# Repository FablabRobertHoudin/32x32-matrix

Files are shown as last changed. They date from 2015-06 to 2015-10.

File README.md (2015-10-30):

# Afficheur LED 32x32 disponible au Fablab

Base information: "RGB Panel Hookup Guide"
https://learn.sparkfun.com/tutorials/rgb-panel-hookup-guide

- Arduino sketch

ESP_32x32.ino 
Support affichage, connection internet en Wifi (2 réseau possible: perso / fablab par ex)
Recupère l'heure en NTP
Affiche les messages publiés par les utilisateurs (PubNub), grace à l'appli Android (APK)

- ESP-12e

Schéma disponible PDF
Attention à l'alimentation:
matrice en 5V (prise USB par ex)
ESP en 3.3V avec régulateur + condensateur 100µF.

http://esp8266.ru/esp8266-pin-register-strapping/

GPIO 0,2,4,5, 12-16 + 9-10 + 1,3 (USART)

GPIO9-10: 
http://smarpl.com/content/esp8266-esp-201-module-freeing-gpio9-and-gpio10

http://www.instructables.com/id/ARDUINO-SOLAR-CHARGE-CONTROLLER-Version-30/

- Application Android

Version très basique, APK dispo

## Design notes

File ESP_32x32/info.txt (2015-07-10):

AT+GMR
AT version:0.23.0.0(Apr 24 2015 21:11:01)
SDK version:1.0.1
Ai-Thinker Technology Co. Ltd.
Apr 27 2015 13:55:14

R0 G0 B0 : top half of display
R1 G1 B1 : bottom half of display
A, B, C, D: which two rows 
LAT(STB): mark end of row data
CLK: mark arrival of data
OE: switch off when one row to next

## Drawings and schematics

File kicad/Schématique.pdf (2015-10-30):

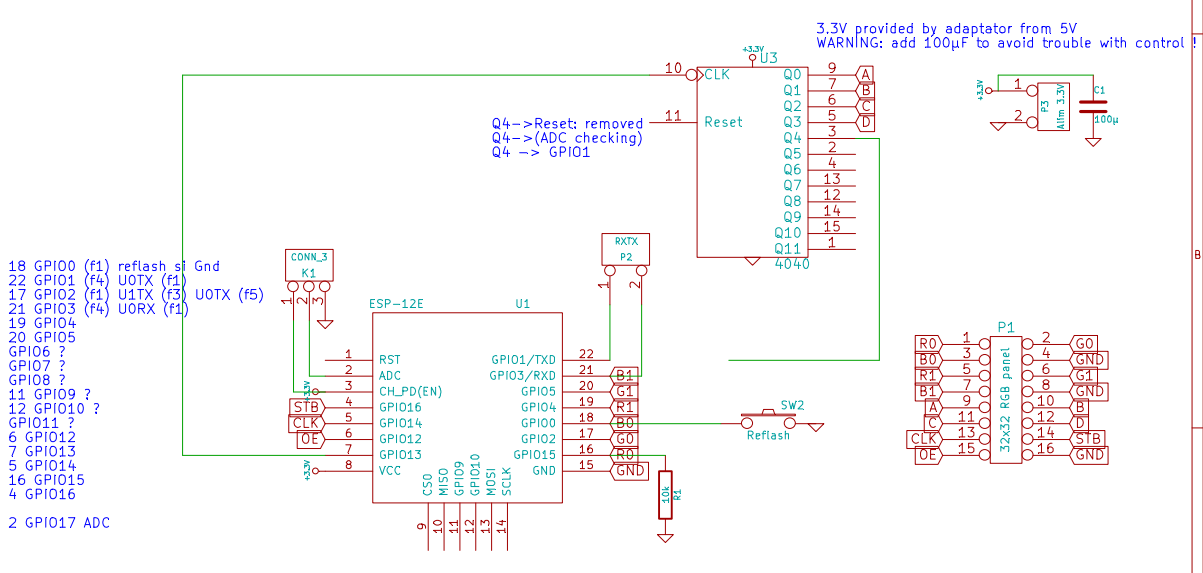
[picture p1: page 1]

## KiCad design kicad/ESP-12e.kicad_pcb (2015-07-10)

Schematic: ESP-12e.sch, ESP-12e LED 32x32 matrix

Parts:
K1: CONN_3
P1: 32x32 RGB panel
P2: RXTX
P3: Alim 3.3V
R1: 10k
SW2: Reflash
U1: ESP-12E
U3: 4040

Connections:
+3.3V: K1.1, P3.1, U1.3, U1.8, U3.16 (VDD)
A: P1.9, U3.9 (Q0)
B: P1.10, U3.7 (Q1)
B0: P1.3, SW2.1, U1.18
B1: P1.7, P2.2 (PM), U1.21
C: P1.11, U3.6 (Q2)
CLK: P1.13, U1.5
D: P1.12, U3.5 (Q3)
G0: P1.2, U1.17
G1: P1.6, U1.20
GND: K1.3, P1.4, P1.8, P1.16, P3.2 (PM), R1.2, SW2.2, U1.15, U3.8 (VSS)
unnamed: P2.1, U1.22
unnamed: U3.3 (Q4), U3.11 (Reset)
unnamed: K1.2 (PM), U1.2
unnamed: U1.7, U3.10 (CLK)
OE: P1.15, U1.6
R0: P1.1, R1.1, U1.16
R1: P1.5, U1.19
STB: P1.14, U1.4

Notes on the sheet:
18 GPIO0 (f1) reflash si Gnd 22 GPIO1 (f4) U0TX (f1) 17 GPIO2 (f1) U1TX (f3) U0TX (f5) 21 GPIO3 (f4) U0RX (f1) 19 GPIO4 20 GPIO5 GPIO6 ? GPIO7 ? GPIO8 ? 11 GPIO9 ? 12 GPIO10 ? GPIO11 ? 6 GPIO12 7 GPIO13 5 GPIO14 16 GPIO15 4 GPIO16 2 GPIO17 ADC

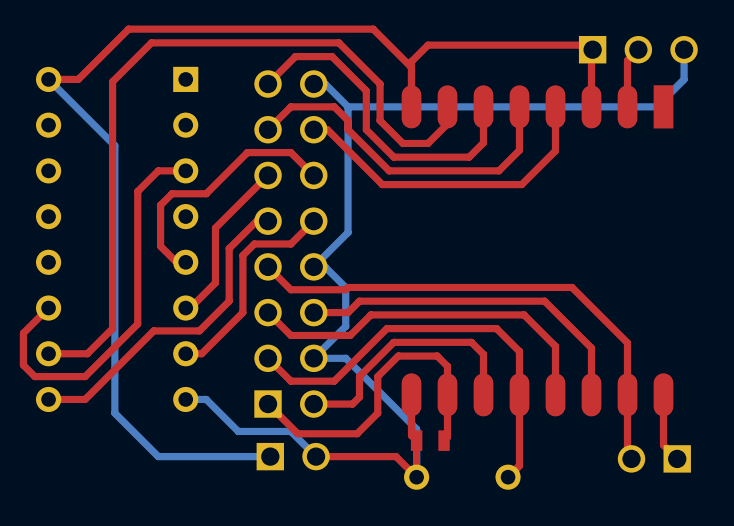
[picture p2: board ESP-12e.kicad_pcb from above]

Board: 2 copper layers, 8 parts (0 on the bottom side), 19 nets.

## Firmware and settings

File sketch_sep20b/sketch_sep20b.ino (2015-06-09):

/* Dependencies */
#include <MsTimer2.h>
#include <Console.h>
/* Compile time constants */
static const byte NB_HORIZONTAL_MATRIX = 2;
static const byte NB_VERTICAL_MATRIX = 1;
static const byte NB_LINES_PER_MATRIX = 32; // MUST be a power of 2
static const byte NB_COLUMNS_PER_MATRIX = 32; // MUST be a power of 2
static const byte MATRIX_SCANLINE_SIZE = 16; // MUST be 8, 16 or 32
static const byte NB_LINES_COUNT = NB_VERTICAL_MATRIX * NB_LINES_PER_MATRIX;
static const byte NB_COLUMNS_COUNT = NB_HORIZONTAL_MATRIX * NB_COLUMNS_PER_MATRIX;
/* Pin mapping */
#if defined(__AVR_ATmega2560__) // For Arduino Mega2560
// R1, G1, B1, R2, G2, B2 hard-wired on PA2~PA7
// A, B, C, D hard-wired on PF0~PF3
// CLK, OE, LAT hard-wired on PB3~PB1 and LED PB7
#define DATA_PORT PORTA
#define DATA_DDR DDRA
#define ADDR_PORT PORTF
#define ADDR_DDR DDRF
#define CTRL_PORT PORTB
#define CTRL_PIN PINB
#define CTRL_DDR DDRB
#define CTRL_CLK_PIN (1 << 3)
#define CTRL_OE_PIN (1 << 2)
#define CTRL_LAT_PIN (1 << 1)
#define CTRL_LED_PIN (1 << 7)
#elif defined(__AVR_ATmega1284P__) // For ATmega1284P based controller board
// R1, G1, B1, R2, G2, B2 hard-wired on PC2~PC7
// LED, CLK, LAT, OE hard-wired on PD4~PD7
// A, B, C, D hard-wired on PB0~PB3
#define DATA_DDR DDRC
#define DATA_PORT PORTC
#define ADDR_DDR DDRB
#define ADDR_PORT PORTB
#define CTRL_DDR DDRD
#define CTRL_PIN PIND
#define CTRL_PORT PORTD
#define CTRL_LED_PIN (1 << 4)
#define CTRL_CLK_PIN (1 << 5)
#define CTRL_LAT_PIN (1 << 6)
#define CTRL_OE_PIN (1 << 7)
#else // For Arduino UNO
// R1, G1, B1, R2, G2, B2 hard-wired on PD2~PD7
// A, B, C, D hard-wired on PC0~PC3
// CLK, OE, LAT hard-wired on PB0~PB2 and LED PB5
#define DATA_PORT PORTD
#define DATA_DDR DDRD
#define ADDR_PORT PORTC
#define ADDR_DDR DDRC
#define CTRL_PORT PORTB
#define CTRL_PIN PINB
#define CTRL_DDR DDRB
#define CTRL_CLK_PIN (1 << 0)
#define CTRL_OE_PIN (1 << 1)
#define CTRL_LAT_PIN (1 << 2)
#define CTRL_LED_PIN (1 << 5)
#endif
#define CTRL_MASK (CTRL_CLK_PIN | CTRL_OE_PIN | CTRL_LAT_PIN | CTRL_LED_PIN)
/**
* Framebuffer for RGB
*
* Array format : [scan line index] [interlaced pixels data stream R, G, B]
* Data format : ... [R1 G1 B1][R2, G2, B2] ...
*/
static volatile byte framebuffer[MATRIX_SCANLINE_SIZE][(NB_LINES_COUNT / MATRIX_SCANLINE_SIZE) * (NB_COLUMNS_COUNT / 8) * 3];

unsigned char *plogoActuel;
const unsigned char TVOlogo[32][4]  = {
    // modif Emmanuel.
    {0xff,0xFF,0xFF,0xFF},
    {0x00,0x00,0x00,0x00},
    {0xff,0xFF,0xFF,0xFF},
    {0x00,0x00,0x00,0x00},
    {0xff,0xFF,0xFF,0xFF},
    {0x00,0x00,0x00,0x00},
    {0xff,0xFF,0xFF,0xFF},
    {0x00,0x00,0x00,0x00},
    {0xff,0xFF,0xFF,0xFF},
    {0x00,0x00,0x00,0x00},
    {0xff,0xFF,0xFF,0xFF},
    {0x00,0x00,0x00,0x00},
    {0xff,0xFF,0xFF,0xFF},
    {0x00,0x00,0x00,0x00},
    {0xff,0xFF,0xFF,0xFF},
    {0x00,0x00,0x00,0x00},
    {0xff,0xFF,0xFF,0xFF},
    {0x00,0x00,0x00,0x00},
    {0xff,0xFF,0xFF,0xFF},
    {0x00,0x00,0x00,0x00},
    {0xff,0xFF,0xFF,0xFF},
    {0x00,0x00,0x00,0x00},
    {0xff,0xFF,0xFF,0xFF},
    {0x00,0x00,0x00,0x00},
    {0xff,0xFF,0xFF,0xFF},
    {0x00,0x00,0x00,0x00},
    {0xff,0xFF,0xFF,0xFF},
    {0x00,0x00,0x00,0x00},
    {0xff,0xFF,0xFF,0xFF},
    {0x00,0x00,0x00,0x00},
    {0xff,0xFF,0xFF,0xFF},
    {0x00,0x00,0x00,0x00},
    
};

const unsigned char  TVOlogo2[32][4] = {
    {0x00,0x00,0x00,0x00},
    {0xff,0xFF,0xFF,0xFF},
    {0x00,0x00,0x00,0x00},
    {0xff,0xFF,0xFF,0xFF},
    {0x00,0x00,0x00,0x00},
    {0xff,0xFF,0xFF,0xFF},
    {0x00,0x00,0x00,0x00},
    {0xff,0xFF,0xFF,0xFF},
    {0x00,0x00,0x00,0x00},
    {0xff,0xFF,0xFF,0xFF},
    {0x00,0x00,0x00,0x00},
    {0xff,0xFF,0xFF,0xFF},
    {0x00,0x00,0x00,0x00},
    {0xff,0xFF,0xFF,0xFF},
    {0x00,0x00,0x00,0x00},
    {0xff,0xFF,0xFF,0xFF},
    {0x00,0x00,0x00,0x00},
    {0xff,0xFF,0xFF,0xFF},
    {0x00,0x00,0x00,0x00},
    {0xff,0xFF,0xFF,0xFF},
    {0x00,0x00,0x00,0x00},
    {0xff,0xFF,0xFF,0xFF},
    {0x00,0x00,0x00,0x00},
    {0xff,0xFF,0xFF,0xFF},
    {0x00,0x00,0x00,0x00},
    {0xff,0xFF,0xFF,0xFF},
    {0x00,0x00,0x00,0x00},
    {0xff,0xFF,0xFF,0xFF},
    {0x00,0x00,0x00,0x00},
    {0xff,0xFF,0xFF,0xFF},
    {0x00,0x00,0x00,0x00},
    {0xff,0xFF,0xFF,0xFF},
};

/**
* Possible color enumeration
*/
enum {
    COLOR_RED,
    COLOR_GREEN,
    COLOR_BLUE,
    COLOR_YELLOW,
    COLOR_CYAN,
    COLOR_PINK,
    COLOR_WHITE,
    COLOR_BLACK
};
/**
* Compute the linear offset in the matrix buffer for the given coordinates.
*
* @param x X position of the pixel.
* @param y Y position of the pixel.
* @return The linear offset in thematrix buffer for the given coordinates.
*/
static inline unsigned int matrixLinearOffset(byte x, byte y) {
    unsigned int xOffset = (x / 8) * (NB_LINES_PER_MATRIX / MATRIX_SCANLINE_SIZE) * 3;
    unsigned int yOffset = (y / NB_LINES_PER_MATRIX) * (NB_LINES_PER_MATRIX / MATRIX_SCANLINE_SIZE) * (NB_COLUMNS_COUNT / 8) * 3;
    unsigned int yInterlacedOffset = ((y & (NB_LINES_PER_MATRIX - 1)) / MATRIX_SCANLINE_SIZE) * 3;
    return yOffset + xOffset + yInterlacedOffset;
}
/**
* Set the color of a pixel in the framebuffer.
*
* @param x X position of the pixel.
* @param y Y position of the pixel.
* @param Color Color to set.
*/
static void setPixelAt(const byte x, const byte y, const byte color) {
    volatile byte* pixel = framebuffer[y & (MATRIX_SCANLINE_SIZE - 1)] + matrixLinearOffset(x, y);
    byte mask = 1 << (x & 7);
    switch(color) {
        case COLOR_RED:
        pixel[0] |= mask;
        pixel[1] &= ~mask;
        pixel[2] &= ~mask;
        break;
        case COLOR_GREEN:
        pixel[0] &= ~mask;
        pixel[1] |= mask;
        pixel[2] &= ~mask;
        break;
        case COLOR_BLUE:
        pixel[0] &= ~mask;
        pixel[1] &= ~mask;
        pixel[2] |= mask;
        break;
        case COLOR_YELLOW:
        pixel[0] |= mask;
        pixel[1] |= mask;
        pixel[2] &= ~mask;
        break;
        case COLOR_CYAN:
        pixel[0] &= ~mask;
        pixel[1] |= mask;
        pixel[2] |= mask;
        break;
        case COLOR_PINK:
        pixel[0] |= mask;
        pixel[1] &= ~mask;
        pixel[2] |= mask;
        break;
        case COLOR_WHITE:
        pixel[0] |= mask;
        pixel[1] |= mask;
        pixel[2] |= mask;
        break;
        default:
        pixel[0] &= ~mask;
        pixel[1] &= ~mask;
        pixel[2] &= ~mask;
        break;
    }
}
/**
* Get the color of a pixel in the framebuffer.
*
* @param x X position of the pixel.
* @param y Y position of the pixel.
* @return The color of the pixel.
*/
static byte getPixelAt(const byte x, const byte y) {
    volatile byte* pixel = framebuffer[y & (MATRIX_SCANLINE_SIZE - 1)] + matrixLinearOffset(x, y);
    byte mask = 1 << (x & 7);
    byte r = !!(pixel[0] & mask);
    byte g = !!(pixel[1] & mask);
    byte b = !!(pixel[2] & mask);
    if(r && !g && !b)
    return COLOR_RED;
    if(!r && g && !b)
    return COLOR_GREEN;
    if(!r && !g && b)
    return COLOR_BLUE;
    if(r && g && !b)
    return COLOR_YELLOW;
    if(!r && g && b)
    return COLOR_CYAN;
    if(r && !g && b)
    return COLOR_PINK;
    if(r && g && b)
    return COLOR_WHITE;
    if(!r && !g && !b)
    return COLOR_BLACK;
}
/** Setup */
void setup() {
    // Setup pins
    DATA_DDR |= 0b11111100; // Data port
    DATA_PORT = DATA_PORT & 0b11;
    ADDR_DDR |= 0b1111; // Addr port
    ADDR_PORT = ADDR_PORT & 0b11110000;
    CTRL_DDR |= CTRL_MASK; // Ctrl port + debug led
    CTRL_PORT = (CTRL_PORT & ~CTRL_MASK) | CTRL_OE_PIN;
    // Init frame buffers (all pixels black)
    memset((void*) framebuffer, 0, MATRIX_SCANLINE_SIZE * (NB_LINES_COUNT / MATRIX_SCANLINE_SIZE) * (NB_COLUMNS_COUNT / 8) * 3);
    // Init refresh timer
    MsTimer2::set(1, refreshDisplay);
    MsTimer2::start();
    
    //Serial.begin(9600);
    plogoActuel = (unsigned char*) &TVOlogo;
    
}
/** Loop */
void loop() {
    
    //Serial.println((int)plogoActuel);
    //Serial.println((int)&TVOlogo);
    
    
    // Demo code
    static byte x = 0;
    static byte y = 0;
    static byte color = COLOR_RED;
    
    unsigned char reste = x%8;
    unsigned char xprime = (x-reste)/8;
    unsigned char valeur = *(plogoActuel+(y*4+xprime));
    unsigned char masque = 0x01 << reste;
    unsigned char coleur = (valeur & masque) >> reste;
    
    if(coleur==0){
        coleur = 2;
        }else{
        coleur =3;
    }
    
    
    setPixelAt(x, y, coleur);
    if(++x == NB_COLUMNS_COUNT) {
        x = 0;
        if(++y == NB_LINES_COUNT) {
            y = 0;
        }
    }
    // No flood delay
    // delay(10);
}


void switchImage() {
    static char current = 0;
    
    if (current)
    plogoActuel = (unsigned char*) &TVOlogo;
    else
    plogoActuel = (unsigned char*) &TVOlogo2;
    
    current = !current;
}



/** Send a whole column pixels bundle */
static void sendColumnBundle(byte **lineBufferPtr) {
    // Hardcoded 1/16 scanline with 32x32 matrix
    // Get RGB values for line N and N + 16
    byte b2 = *(*lineBufferPtr);
    byte g2 = *(--(*lineBufferPtr));
    byte r2 = *(--(*lineBufferPtr));
    byte b1 = *(--(*lineBufferPtr));
    byte g1 = *(--(*lineBufferPtr));
    byte r1 = *(--(*lineBufferPtr));
    --(*lineBufferPtr);
    // MSB FIRST
    DATA_PORT = (DATA_PORT & 0b11) | (!!(r1 & 128) << 2) | (!!(g1 & 128) << 3) | (!!(b1 & 128) << 4) | (!!(r2 & 128) << 5) | (!!(g2 & 128) << 6) | (!!(b2 & 128) << 7);
    CTRL_PIN = CTRL_CLK_PIN;
    CTRL_PIN = CTRL_CLK_PIN; // CLK pulse
    DATA_PORT = (DATA_PORT & 0b11) | (!!(r1 & 64) << 2) | (!!(g1 & 64) << 3) | (!!(b1 & 64) << 4) | (!!(r2 & 64) << 5) | (!!(g2 & 64) << 6) | (!!(b2 & 64) << 7);
    CTRL_PIN = CTRL_CLK_PIN;
    CTRL_PIN = CTRL_CLK_PIN; // CLK pulse
    DATA_PORT = (DATA_PORT & 0b11) | (!!(r1 & 32) << 2) | (!!(g1 & 32) << 3) | (!!(b1 & 32) << 4) | (!!(r2 & 32) << 5) | (!!(g2 & 32) << 6) | (!!(b2 & 32) << 7);
    CTRL_PIN = CTRL_CLK_PIN;
    CTRL_PIN = CTRL_CLK_PIN; // CLK pulse
    DATA_PORT = (DATA_PORT & 0b11) | (!!(r1 & 16) << 2) | (!!(g1 & 16) << 3) | (!!(b1 & 16) << 4) | (!!(r2 & 16) << 5) | (!!(g2 & 16) << 6) | (!!(b2 & 16) << 7);
    CTRL_PIN = CTRL_CLK_PIN;
    CTRL_PIN = CTRL_CLK_PIN; // CLK pulse
    DATA_PORT = (DATA_PORT & 0b11) | (!!(r1 & 8) << 2) | (!!(g1 & 8) << 3) | (!!(b1 & 8) << 4) | (!!(r2 & 8) << 5) | (!!(g2 & 8) << 6) | (!!(b2 & 8) << 7);
    CTRL_PIN = CTRL_CLK_PIN;
    CTRL_PIN = CTRL_CLK_PIN; // CLK pulse
    DATA_PORT = (DATA_PORT & 0b11) | (!!(r1 & 4) << 2) | (!!(g1 & 4) << 3) | (!!(b1 & 4) << 4) | (!!(r2 & 4) << 5) | (!!(g2 & 4) << 6) | (!!(b2 & 4) << 7);
    CTRL_PIN = CTRL_CLK_PIN;
    CTRL_PIN = CTRL_CLK_PIN; // CLK pulse
    DATA_PORT = (DATA_PORT & 0b11) | (!!(r1 & 2) << 2) | (!!(g1 & 2) << 3) | (!!(b1 & 2) << 4) | (!!(r2 & 2) << 5) | (!!(g2 & 2) << 6) | (!!(b2 & 2) << 7);
    CTRL_PIN = CTRL_CLK_PIN;
    CTRL_PIN = CTRL_CLK_PIN; // CLK pulse
    DATA_PORT = (DATA_PORT & 0b11) | (!!(r1 & 1) << 2) | (!!(g1 & 1) << 3) | (!!(b1 & 1) << 4) | (!!(r2 & 1) << 5) | (!!(g2 & 1) << 6) | (!!(b2 & 1) << 7);
    CTRL_PIN = CTRL_CLK_PIN;
    CTRL_PIN = CTRL_CLK_PIN; // CLK pulse
}

static int i = 0;

/** Display scaline refresh routine */
void refreshDisplay() {
    
    i++;
    if (i==1000)
    {
        i=0;
        switchImage();
    }
    
    // Scan line index
    static byte scanlineIndex = 0;
    // Setup control lines and address lines
    CTRL_PORT = (CTRL_PORT & ~CTRL_MASK) | CTRL_OE_PIN | CTRL_LAT_PIN | CTRL_LED_PIN;
    ADDR_PORT = (ADDR_PORT & 0b11110000) | scanlineIndex;
    // Get line buffer
    byte *lineBuffer = (byte*) framebuffer[scanlineIndex];
    lineBuffer += (NB_LINES_COUNT / MATRIX_SCANLINE_SIZE) * (NB_COLUMNS_COUNT / 8) * 3 - 1;
    // For each pixels bundle of matrix 4/4, 3/3, 2/2 or 1/1
    sendColumnBundle(&lineBuffer);
    sendColumnBundle(&lineBuffer);
    sendColumnBundle(&lineBuffer);
    sendColumnBundle(&lineBuffer);
    // For each pixels bundle of matrix 3/4, 2/3, 1/2
    if (NB_HORIZONTAL_MATRIX * NB_VERTICAL_MATRIX >= 2) {
        sendColumnBundle(&lineBuffer);
        sendColumnBundle(&lineBuffer);
        sendColumnBundle(&lineBuffer);
        sendColumnBundle(&lineBuffer);
    }
    // For each pixels bundle of matrix 2/4, 1/3
    if (NB_HORIZONTAL_MATRIX * NB_VERTICAL_MATRIX >= 3) {
        sendColumnBundle(&lineBuffer);
        sendColumnBundle(&lineBuffer);
        sendColumnBundle(&lineBuffer);
        sendColumnBundle(&lineBuffer);
    }
    // For each pixels bundle of matrix 1/4
    if (NB_HORIZONTAL_MATRIX * NB_VERTICAL_MATRIX >= 4) {
        sendColumnBundle(&lineBuffer);
        sendColumnBundle(&lineBuffer);
        sendColumnBundle(&lineBuffer);
        sendColumnBundle(&lineBuffer);
    }
    // Trigger latch
    CTRL_PORT = CTRL_PORT & ~CTRL_MASK;
    // Handle scan line overflow
    if (++scanlineIndex == MATRIX_SCANLINE_SIZE) {
        // Reset scan line index
        scanlineIndex = 0;
    }
}

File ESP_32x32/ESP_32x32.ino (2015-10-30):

#include "ESP8266WiFi.h"
#include <Ticker.h>
#include "Matrix32x32.h"
#include "PubNub.h"
#include "NTP.h"

extern const char* ssid2;
extern const char* password2;
extern const char* ssid1;
extern const char* password1;

extern const char* pubKey;
extern const char* subKey;

PubNub pubnub(pubKey, subKey);

Ticker tick;

void setup() {
  int loop = 0;
  // put your setup code here, to run once:
  //Serial.begin(115200);

  WiFi.begin(ssid1, password1);
  while ((WiFi.status() != WL_CONNECTED) && (loop++ < 20)) {
    delay(500);
    //Serial.print(".");
  }

if (WiFi.status() != WL_CONNECTED) {
  //Serial.print("2");
  WiFi.begin(ssid2, password2);

  loop=0;
  while ((WiFi.status() != WL_CONNECTED) && (loop++ < 20)) {
    delay(500);
    //Serial.print(".");
  }
}

  //pubnub.publish("Matrix", "\"OK\"");

  Ntp.sendNTPpacket(NTP::timeServer); // send an NTP packet to a time server

/*
  // Start the server
  server.begin();
  Serial.println("Server started");
*/

  M.init();
  // 0.0010 OK visuellement mini
  // 0.0015 OK visuellement
  // 0.0020 bof
  //tick.attach_ms(2, update);
  tick.attach(0.0015, update);

  // Print the IP address
  IPAddress ip = WiFi.localIP();
  //Serial.println(ip);
  //Serial.end();


  M.display(0, 0b00000111, "Fablab Robert-Houdin");
  //M.display(1, 0b00000100, "IP: "+ip);

}

//bool dosubscribe = 0;
int substate=0;
byte demult = 0;
void update()
{
  M.update();
  
  if (++demult > 100) {
    demult = 0;
    if (!M.write(0)) {
        String line = "  Fablab Robert-Houdin  ";
        //line = line + timetoken;
        M.display(0, 0b00000111, line); // White
    }
    
    if (!M.write(1)) {
      //dosubscribe = 1;
      substate = 1;
        //M.display(1, 0b00000100, "TBD...");
    }
    
    if (!M.write(3)) {
      char line[10];
      Ntp.update();
      //String t = "" + Ntp._h + ":" + Ntp._m + ":" + Ntp._s;
      strcpy(line, "__:__:__\0\0");
      int x;
      x = Ntp._h; // (t % 86400L) / 3600; // hour
      line[0] = '0'+(x/10);
      line[1] = '0'+(x % 10);
      x = Ntp._m; // (t % 3600) / 60; // min
      line[3] = '0'+(x/10);
      line[4] = '0'+(x % 10);
      x = Ntp._s; // (t % 60); // sec
      line[6] = '0'+(x/10);
      line[7] = '0'+(x % 10);
      M.display(3, 0b00000010, String(line)); // Green
    }
  }
}

WiFiClient subsciber;
void loop()
{
  if (!Ntp.parsed) {
    Ntp.checkPacket();
        M.display(1, 0b00000100, "Time OK"); // Blue
  } else {
      if (substate==1) {
        String line = pubnub.subscribe("Matrix");
        M.display(1, 0b00000001, line); // Red
        substate++;

/*
      } else if (substate==10) {
      if (subsciber.available()>1) {
          String line = subsciber.readString();
          //M.display(1, 0b00000100, "read:"+line.length());
          int l = line.length();
          int i = line.indexOf("\r\n\r\n");
          line = line.substring(i+4);
          line.substring(line.length()-19).toCharArray(timetoken, 18);
          timetoken[18] = '\0';
          M.display(1, 0b00000001, line); // Red
        substate++;
      } else {
        //M.display(1, 0b00000100, "tbd");
      }
*/
      
    }

/*
    if (substate==0) {
      //tick.detach();
      if (subsciber.connect("pubsub.pubnub.com", 80)) {
          subsciber.print("GET /subscribe/sub-c-27e78ea8-9b24-11e4-91be-02ee2ddab7fe/ESP/0/");
          subsciber.print(timetoken);
          subsciber.print(" HTTP/1.0\r\n\r\n");
        substate++;
        M.display(1, 0b00000100, "-"); // Blue
      }
      //tick.attach(0.0015, update);
    }
*/
  }

  


/*
  WiFiClient client = server.available();
  if (!client) {
    return;
  }

  // Wait until the client sends some data
  //Serial.println("new client");
  while(!client.available()){
    delay(1);
  }

  // Read the first line of the request
  String req = client.readStringUntil('\r');
  //Serial.println(req);
  // Copy request to line !!!
      //strcpy(line, req);
      // GET /msg=XXXX HTTP/1.1
      M.display(1, 0b00000001, req.substring(10, req.length()-8));
      
  client.flush();

  // Send the response to the client
  client.print("HTTP/1.1 200 OK\r\nContent-Type: text/html\r\n\r\n<!DOCTYPE HTML>\r\n<html>");
  client.print("<form method='GET'>Message: <input type='text' name='msg'/></form>");
  client.print("</html>");
  //client.close();
*/
}

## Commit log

2015-06-09 Creation
    description & initial Arduino sketch
2015-06-09 Affichage "Fablab Robert-Houdin"
    Version Arduino Uno "Fablab Robert-Houdin"
    Dispo au 1 juin 2015
2015-07-10 First working test
    Added Kicad schema
    Arduino ESP test
    [ArduinoUno.sch, ESP-12e.kicad_pcb, ESP-12e.sch]
2015-10-30 Working version
    - Correction de code (fonctionnel)
    - Schéma circuit
    - Application Android (APK, version de base)
    [ESP_32x32.ino, Matrix32x32.cpp]
